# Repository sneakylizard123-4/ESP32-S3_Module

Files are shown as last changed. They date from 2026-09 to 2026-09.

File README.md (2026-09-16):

# ESP32-S3 Module

A Feather-like ESP32-S3 Module with IP5306 Battery charging and a built in Neopixel

## Custom Features
- IP5306 PMIC
- Neopixel, User and Power led
- ESP32-S3-1/1U MCU

## PCB Design

The Module is a 4 layer pcb with a dedicated ground inner layer

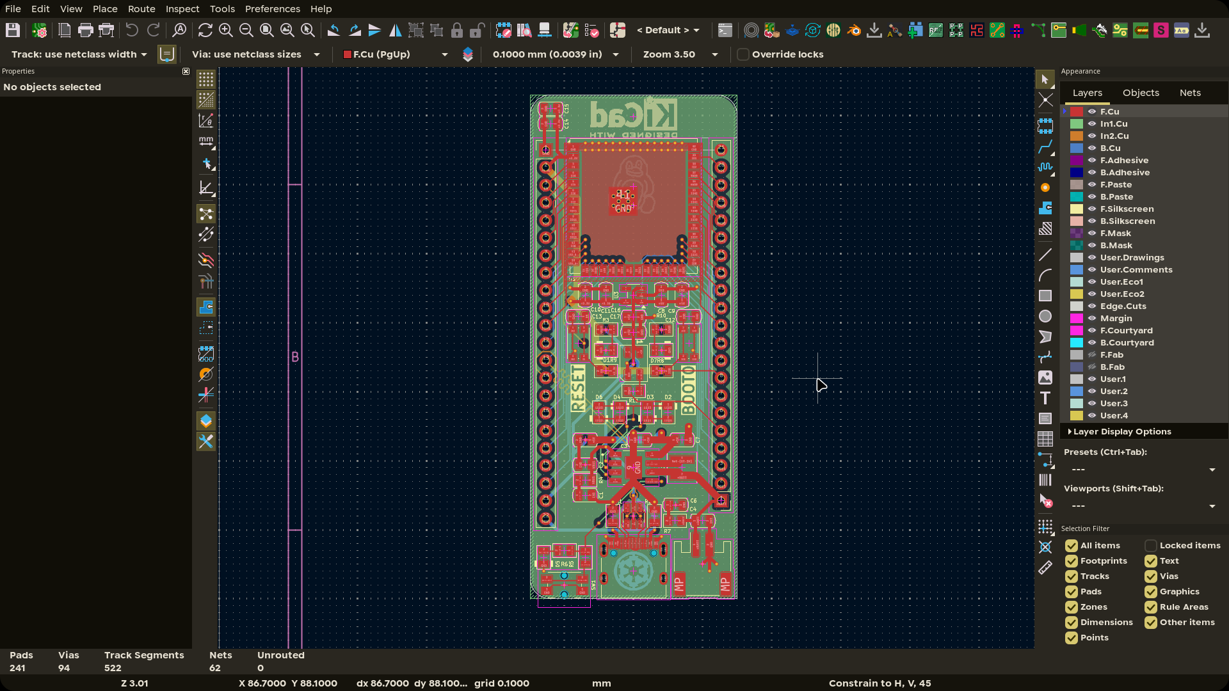
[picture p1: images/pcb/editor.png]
PCB 3D / layout image


It is built off the ESP32-S3 series MCU to support WiFi/Bluetooth/Zigbee
It has built in USB ESD protection.
It can be programmed using UART/FTDI or throught the ESP32-S3's Native USB.

## Firmware

As the Module uses an ESP32, it can be programmed using ESP-IDF, Arduino IDE, or Platformio.
To enter program mode:
1. Hold BOOT0
2. Press RESET
3. Release BOOT0
4. Start Flashing

## BOM (Bill of Materials)

| Ref | Value | LCSC # | MPN | Manufacturer | Footprint | Qty | Unit $ | Ext $ | Link |
|-----|---|---|-----|---|---|-----|---|---|---|
| C1,C2,C4,C6,C9,C11,C15,C17 | 10uF 25V X5R | C15850 | CL21A106KAYNNNE | Samsung | 0805 | 8 | 0.0871 | 0.6968 | [LCSC](https://www.lcsc.com/product-detail/C15850.html) |
| C8,C10,C12,C13,C14,C16 | 100nF 50V X7R | C1711 | CC0805KRX7R9BB104 | YAGEO | 0805 | 6 | 0.0266 | 0.1596 | [LCSC](https://www.lcsc.com/product-detail/C1711.html) |
| C3,C5,C7 | 22uF 25V X5R | C86816 | GRM21BR61E226ME44L | muRata | 0805 | 3 | 0.0698 | 0.2094 | [LCSC](https://www.lcsc.com/product-detail/C86816.html) |
| D1-D7 | Orange LED 0805 | C965813 | XL-2012UOC | XINGLIGHT | 0805 | 7 | 0.0096 | 0.0672 | [LCSC](https://www.lcsc.com/product-detail/C965813.html) |
| D8 | WS2812B | C2761795 | WS2812B-B/T | Worldsemi | PLCC4 5050 | 1 | 0.0940 | 0.0940 | [LCSC](https://www.lcsc.com/product-detail/C2761795.html) |
| J1 | USB-C Receptacle 16P | C165948 | TYPE-C-31-M-12 | Korean Hroparts Elec | SMD | 1 | 0.1724 | 0.1724 | [LCSC](https://www.lcsc.com/product-detail/C165948.html) |
| J2 | JST PH 2P 2mm | C131337 | B2B-PH-K-S(LF)(SN) | JST | Through Hole | 1 | 0.0356 | 0.0356 | [LCSC](https://www.lcsc.com/product-detail/C131337.html) |
| J3 | Pin Header 1x22 2.54mm | C41375941 | HC-PZ254-11.5L-1x22PZ | Hong Cheng | Through Hole | 1 | 0.1200 | 0.1200 | [LCSC](https://www.lcsc.com/product-detail/C41375941.html) |
| J4 | Pin Header 1x21 2.54mm | C49569644 | 2011-1X21G00SB | WingTAT | Through Hole | 1 | 0.1000 | 0.1000 | [LCSC](https://www.lcsc.com/product-detail/C49569644.html) |
| L1 | 1uH Shielded Inductor | C5355380 | XFL4020-102MEC | Coilcraft | SMD 4x4mm | 1 | 2.5134 | 2.5134 | [LCSC](https://www.lcsc.com/product-detail/C5355380.html) |
| R1,R2 | 5.1k 1% 0805 | C27834 | 0805W8F5101T5E | UNI-ROYAL | 0805 | 2 | 0.0065 | 0.0130 | [LCSC](https://www.lcsc.com/product-detail/C27834.html) |
| R3,R5,R6,R8,R9,R10 | 10k 1% 0805 | C2907219 | FRC0805F1002TS | FOJAN | 0805 | 6 | 0.0035 | 0.0210 | [LCSC](https://www.lcsc.com/product-detail/C2907219.html) |
| R11 | 330 1% 0805 | C2889518 | 0805 1% 330 OHM | VO | 0805 | 1 | 0.0050 | 0.0050 | [LCSC](https://www.lcsc.com/product-detail/C2889518.html) |
| R4,R7 | 2R 1% 0805 | C114246 | RC0805FR-072RL | YAGEO | 0805 | 2 | 0.0261 | 0.0522 | [LCSC](https://www.lcsc.com/product-detail/C114246.html) |
| SW1 | Tactile Switch EVQPUD | C388885 | EVQPUD02K | PANASONIC | SMD | 1 | 0.2299 | 0.2299 | [LCSC](https://www.lcsc.com/product-detail/C388885.html) |
| SW2,SW3 | Tactile Switch KMR2 | C72443 | KMR221GLFS | C&K | SMD | 2 | 0.6515 | 1.3030 | [LCSC](https://www.lcsc.com/product-detail/C72443.html) |
| U1 | USBLC6-2SC6 | C7519 | USBLC6-2SC6 | ST | SOT-23-6 | 1 | 0.0896 | 0.0896 | [LCSC](https://www.lcsc.com/product-detail/C7519.html) |
| U2 | IP5306 | C181692 | IP5306 | INJOINIC | ESOP-8 | 1 | 0.2989 | 0.2989 | [LCSC](https://www.lcsc.com/product-detail/C181692.html) |
| U3 | TLV75733PDBV | C485517 | TLV75733PDBVR | TI | SOT-23-5 | 1 | 0.1819 | 0.1819 | [LCSC](https://www.lcsc.com/product-detail/C485517.html) |
| U4 | ESP32-S3-WROOM-1U | C2913202 | ESP32-S3-WROOM-1-N8 | ESPRESSIF | SMD WROOM | 1 | 3.1300 | 3.1300 | [LCSC](https://www.lcsc.com/product-detail/C2913202.html) |
| PCB | Bare PCB | — | — | — | — | 1 | 1.5000 | 1.5000 | — |
| **Total** | — | — | — | — | — | **49** | — | **10.9929** | — |

Full CSVs: [LCSC BOM](BOM.csv)
[KiCad generated BOM](kicad/production/bom.csv)
[Pick and place](kicad/production/positions.csv)

## Production

This board assumes JLCPCB's standard 4 layer
- HASL Lead Free
- 1.6mm thick board

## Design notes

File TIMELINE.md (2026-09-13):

# Timeline

Chronology of the ESP32-S3 Module design work, reconstructed from KiCad Local History (`kicad/.history`, 672 auto-snapshots, all authored by "KiCad") and the project git history (`esp32-s3` repo, 3 commits by sneakylizard123-4). All times are local (UTC-7).

## Sep 2, 2026 (evening)

- 21:05: Project started. Root schematic created in KiCad: initial autosave followed by 3 quick saves. First components placed on a single flat sheet. (~5 min)

## Sep 3, 2026 (morning)

- 11:09-11:10: Short schematic session, more components added to the root sheet. (~5 min)

## Sep 13, 2026 (main work day)

### Schematic build-out (10:53 - 11:21)

- 10:53-11:12: Heavy edit burst on the root schematic (~64 saves). Full design laid out on one sheet: ESP32-S3-WROOM-1U MCU, USB-C with ESD clamp and CC resistors, IP5306 power management, TLV75733 3.3V LDO, header breakouts, buttons, LEDs.
- 11:13: PCB file created from the schematic in the PCB editor, then back to schematic work.
- 11:14-11:21: Final pass on the root sheet (net labels, cleanup).

### Hierarchical refactor (11:22 - 11:37)

- 11:22-11:25: Split the flat design into hierarchical subsheets. Creation order by first save: `usb.kicad_sch` (11:22), `power.kicad_sch` (11:23), `esp32.kicad_sch` (11:24), `connector.kicad_sch` (11:25). Root sheet now holds the 4 sheet symbols.
- 11:26-11:29: Wiring the sheet symbols and kicad_pcb library/footprint sync on the root sheet.
- 11:30-11:37: Power subsheet brought up in detail (IP5306 battery charger/boost, LDO, inductive buck components, status LEDs).

### Subsheet polish + first layout (11:39 - 12:25)

- 11:39-11:45: Round of edits across all four subsheets; PCB footprint sync starts.
- 11:42-11:58: Early PCB placement: footprints dropped and rough positioning on the board.
- 11:59-12:01: Schematic fixes needed to match footprint pins.
- 12:02-12:16: ESP32 subsheet detail work (pull-up resistors, decoupling, button wiring, WS2812B LED), connector sheet edits.
- 12:17-12:25: Continued component placement on the PCB.
- (_break, ~1 hour_)

### Board layout (13:26 - 13:56)

- 13:26-13:56: Long, steady PCB session - component placement finalized across the board (relays, ~90 saves). Occasional connector subsheet edits at 13:26 while iterating on the board.

### Board routing (14:14 - 15:19)

- 14:14-14:16: A couple more connector/power sheet touches, then pure PCB work.
- 14:17-14:24: Routing burst, heavy activity (~8 saves/min).
- 14:25-14:34: Routing continues (edge pours, power nets).
- 14:35-14:37: Last schematic tweaks on connector and usb subsheets to fix layout-drive issues; board re-synced.
- 14:38-15:19: Final routing marathon (~150 saves). Ends with PCB Save at 15:19:10, then production output generated at 15:19: `production/ESP32-S3_Module.zip` (gerbers), `bom.csv`, `positions.csv`, `designators.csv`, `netlist.ipc`.

### Packaging (15:19 - 15:42)

- 15:21: STEP 3D model exported to `cad/ESP32-S3_Module.step` (6.3 MB, board + component 3D models).
- 15:35: Project git repo initialized. First commit `e5d1c9f` "start": full KiCad sources, production files, STEP, README skeleton, and 7 rendered PNGs (5 schematic sheets + top/bottom PCB renders).
- 15:38: Commit `6953c8a` "readm": README trimmed/edited.
- ~15:39-15:41: PCB editor screenshot captured (`images/pcb/editor.png`). Empty `BOM.csv` and `JOURNAL.md` placeholders created.
- 15:42: Commit `c15c209` "a": screenshots reorganized into `images/schematic/`, `images/renders/`, `images/pcb/`, plus the README/BOM/JOURNAL updates.

## Totals (approx.)

- Sep 2: ~5 min
- Sep 3: ~5 min
- Sep 13: ~4 h 20 min across the day (schematic ~1.5 h, layout+route ~2.5 h, breaks excluded)

## Sources

- `kicad/.history` - KiCad Local History git repo (672 snapshots, Sep 2 -> Sep 13) by "KiCad"
- Project git repo - 3 commits (`start`, `readm`, `a`) by sneakylizard123-4, Sep 13 15:35-15:42

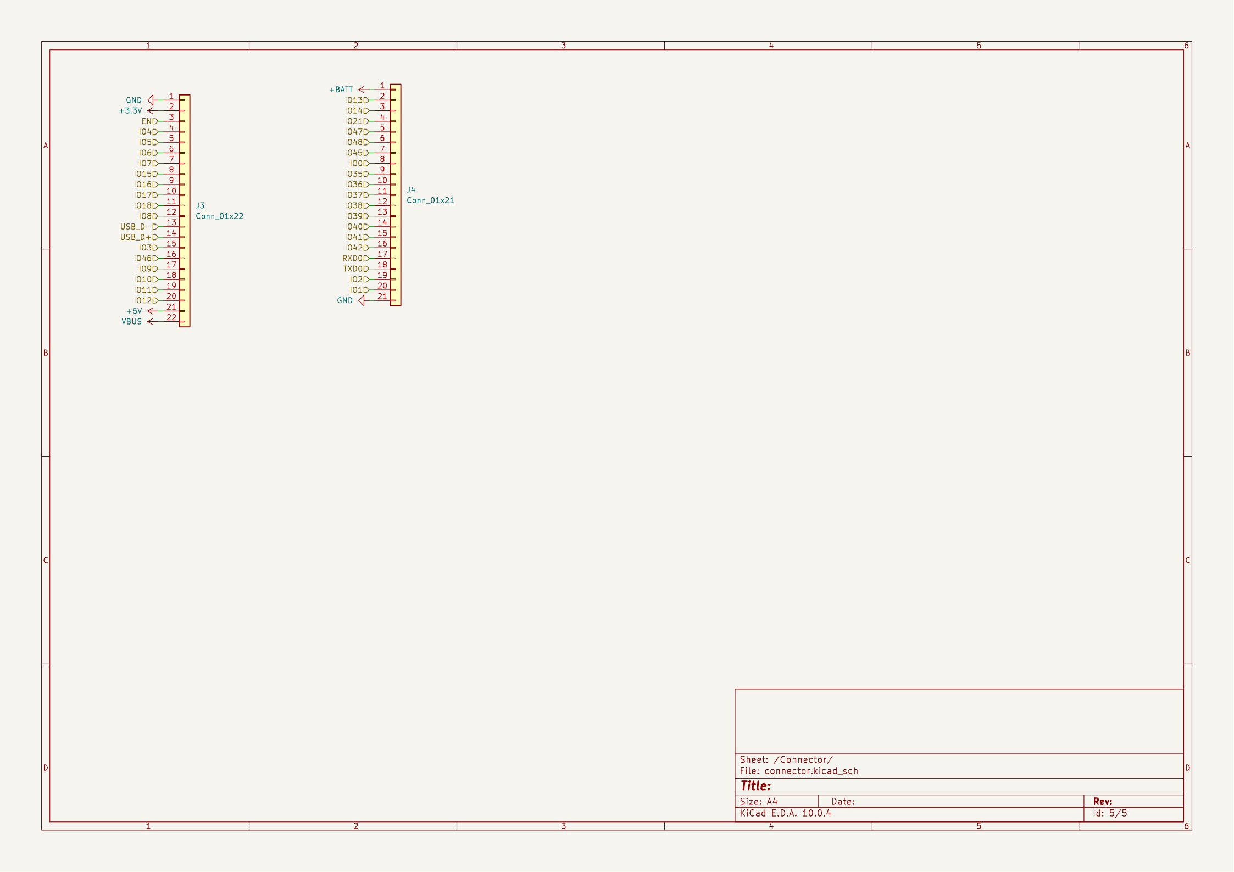
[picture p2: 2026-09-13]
images/schematic/05-connector.png

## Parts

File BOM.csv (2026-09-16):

Ref | Value | LCSC# | MPN | Manufacturer | Footprint | Qty | Unit Price($) | Ext Price($) | Supplier Link
C1, C11, C15, C17, C2, C4, C6, C9 | 10uF 25V X5R | C15850 | CL21A106KAYNNNE | Samsung | 0805 | 8 | 0.0871 | 0.6968 | https://www.lcsc.com/product-detail/C15850.html
C10, C12, C13, C14, C16, C8 | 100nF 50V X7R | C1711 | CC0805KRX7R9BB104 | YAGEO | 0805 | 6 | 0.0266 | 0.1596 | https://www.lcsc.com/product-detail/C1711.html
C3, C5, C7 | 22uF 25V X5R | C86816 | GRM21BR61E226ME44L | muRata | 0805 | 3 | 0.0698 | 0.2094 | https://www.lcsc.com/product-detail/C86816.html
D1, D2, D3, D4, D5, D6, D7 | Orange LED 0805 | C965813 | XL-2012UOC | XINGLIGHT | 0805 | 7 | 0.0096 | 0.0672 | https://www.lcsc.com/product-detail/C965813.html
D8 | WS2812B | C2761795 | WS2812B-B/T | Worldsemi | PLCC4 5050 | 1 | 0.0940 | 0.0940 | https://www.lcsc.com/product-detail/C2761795.html
J1 | USB-C Receptacle 16P | C165948 | TYPE-C-31-M-12 | Korean Hroparts Elec | SMD | 1 | 0.1724 | 0.1724 | https://www.lcsc.com/product-detail/C165948.html
J2 | JST PH 2P 2mm | C131337 | B2B-PH-K-S(LF)(SN) | JST | Through Hole | 1 | 0.0356 | 0.0356 | https://www.lcsc.com/product-detail/C131337.html
J3 | Pin Header 1x22 2.54mm | C41375941 | HC-PZ254-11.5L-1x22PZ | Hong Cheng | Through Hole | 1 | 0.1200 | 0.1200 | https://www.lcsc.com/product-detail/C41375941.html
J4 | Pin Header 1x21 2.54mm | C49569644 | 2011-1X21G00SB | WingTAT | Through Hole | 1 | 0.1000 | 0.1000 | https://www.lcsc.com/product-detail/C49569644.html
L1 | 1uH Shielded Inductor | C5355380 | XFL4020-102MEC | Coilcraft | SMD 4x4mm | 1 | 2.5134 | 2.5134 | https://www.lcsc.com/product-detail/C5355380.html
R1, R2 | 5.1k 1% 0805 | C27834 | 0805W8F5101T5E | UNI-ROYAL | 0805 | 2 | 0.0065 | 0.0130 | https://www.lcsc.com/product-detail/C27834.html
R10, R3, R5, R6, R8, R9 | 10k 1% 0805 | C2907219 | FRC0805F1002TS | FOJAN | 0805 | 6 | 0.0035 | 0.0210 | https://www.lcsc.com/product-detail/C2907219.html
R11 | 330 1% 0805 | C2889518 | 0805 1% 330 OHM | VO | 0805 | 1 | 0.0050 | 0.0050 | https://www.lcsc.com/product-detail/C2889518.html
R4, R7 | 2R 1% 0805 | C114246 | RC0805FR-072RL | YAGEO | 0805 | 2 | 0.0261 | 0.0522 | https://www.lcsc.com/product-detail/C114246.html
SW1 | Tactile Switch EVQPUD | C388885 | EVQPUD02K | PANASONIC | SMD | 1 | 0.2299 | 0.2299 | https://www.lcsc.com/product-detail/C388885.html
SW2, SW3 | Tactile Switch KMR2 | C72443 | KMR221GLFS | C&K | SMD | 2 | 0.6515 | 1.3030 | https://www.lcsc.com/product-detail/C72443.html
U1 | USBLC6-2SC6 | C7519 | USBLC6-2SC6 | ST | SOT-23-6 | 1 | 0.0896 | 0.0896 | https://www.lcsc.com/product-detail/C7519.html
U2 | IP5306 | C181692 | IP5306 | INJOINIC | ESOP-8 | 1 | 0.2989 | 0.2989 | https://www.lcsc.com/product-detail/C181692.html
U3 | TLV75733PDBV | C485517 | TLV75733PDBVR | TI | SOT-23-5 | 1 | 0.1819 | 0.1819 | https://www.lcsc.com/product-detail/C485517.html
U4 | ESP32-S3-WROOM-1U | C2913202 | ESP32-S3-WROOM-1-N8 | ESPRESSIF | SMD WROOM | 1 | 3.1300 | 3.1300 | https://www.lcsc.com/product-detail/C2913202.html
PCB | Bare PCB |  |  |  |  | 1 | 1.5000 | 1.5000
Total |  |  | Components (9.4929) + PCB (1.50) = Total |  |  |  |  | 10.9929

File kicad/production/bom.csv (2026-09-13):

Designator | Footprint | Quantity | Value | LCSC Part #
C1, C11, C15, C17, C2, C4, C6, C9 | 0805 | 8 | 10uF
C10, C12, C13, C14, C16, C8 | 0805 | 6 | 100nF
C3, C5, C7 | 0805 | 3 | 22uF
D1, D2, D3, D4, D5, D6, D7 | 0805 | 7 | LED
D8 | LED_WS2812B-Mini_PLCC4_3.5x3.5mm | 1 | WS2812B
J1 | USB_C_Receptacle_HRO_TYPE-C-31-M-12 | 1 | USB_C_Receptacle_USB2.0_16P
J2 | JST_PH_S2B-PH-SM4-TB_1x02-1MP_P2.00mm_Horizontal | 1 | Conn_01x02
J3 | PinHeader_1x22_P2.54mm_Vertical | 1 | Conn_01x22
J4 | PinHeader_1x21_P2.54mm_Vertical | 1 | Conn_01x21
L1 | L_Coilcraft_XxL4020 | 1 | 1uH XFL4020-102MEC
R1, R2 | 0805 | 2 | 5.1k
R10, R3, R5, R6, R8, R9 | 0805 | 6 | 10k
R11 | 0805 | 1 | 330
R4, R7 | 0805 | 2 | 2
SW1 | Panasonic_EVQPUM_EVQPUD | 1 | SW_Push
SW2, SW3 | SW_Push_1P1T_NO_CK_KMR2 | 2 | SW_Push
U1 | SOT-23-6 | 1 | USBLC6-2SC6
U2 | SOP127P600X165-9N | 1 | IP5306
U3 | SOT-23-5 | 1 | TLV75733PDBV
U4 | ESP32-S3-WROOM-1U | 1 | ESP32-S3-WROOM-1

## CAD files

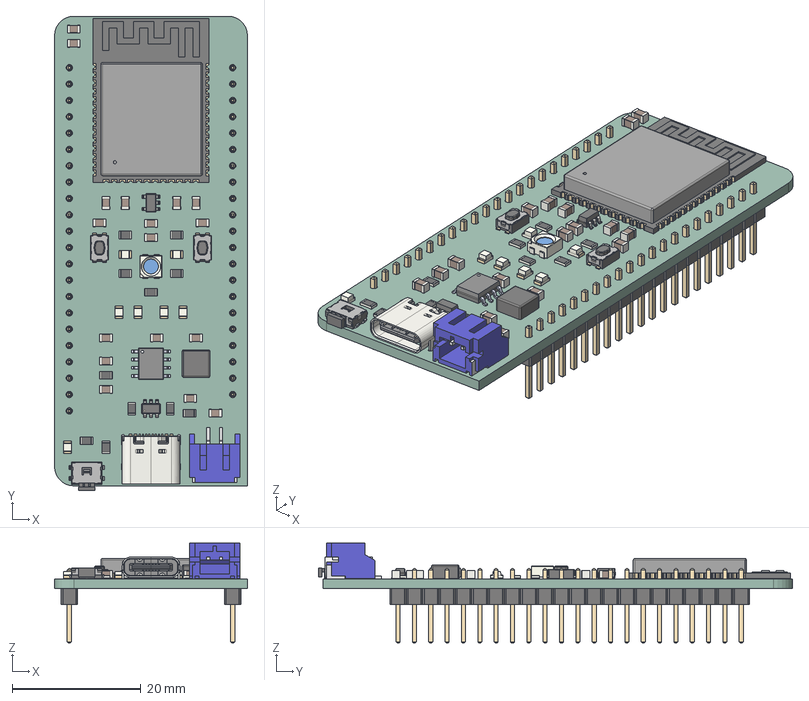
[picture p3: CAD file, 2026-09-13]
cad/ESP32-S3_Module.step
30.0 x 73.8 x 15.5 mm
SW_Push_1P1T_NO_CK_KMR2 x 2
C_0805_2012Metric x 17
LED_0805_2012Metric x 7
R_0805_2012Metric x 11
ESP32-S3-WROOM-1
IP5306
Panasonic_EVQPUM_EVQPUD
SOT-23-6
SOT-23-5
S2B-PH-SM4
L_Coilcraft_XAL4020-XXX
USB_C_Receptacle_16P_TopMnt_Horizontal_GCT_USB4105-xx-A
LED_WS2812B-Mini_PLCC4_3.5x3.5mm_P1.8mm
PinHeader_1x22_P254mm_Vertical
PinHeader_1x21_P254mm_Vertical
ESP32-S3_Module_PCB

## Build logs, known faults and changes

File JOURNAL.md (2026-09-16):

---
title: ESP32-S3 Module
author: sneakylizard123-4
description: Like a Feather
created_at: 2026-09-02
---

# September 2

Started the ESP32-S3 Project.
I wanted a quick and easy way to prototype my projects and all of my other esp32's were either:
1. Not esp32 (esp8266)
2. No USB (needed FTDI)
3. Not esp32-s3

Placed first components like USB-C and the main ESP32 MCU

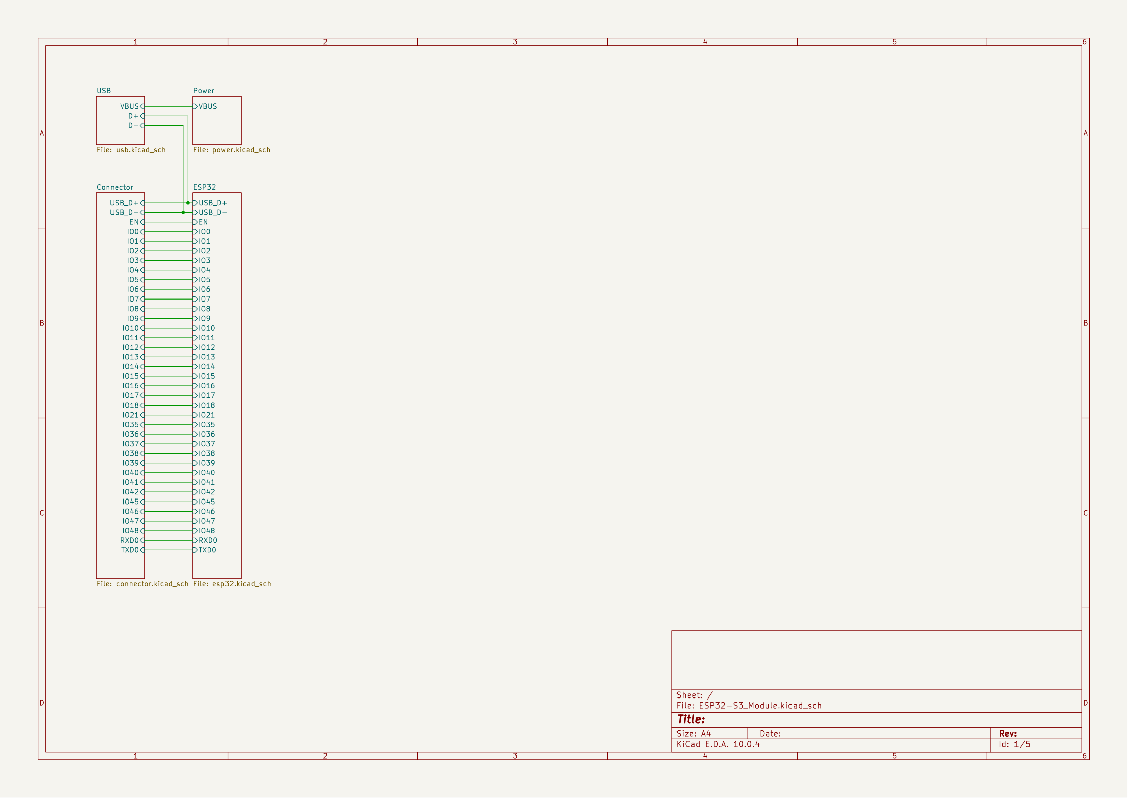
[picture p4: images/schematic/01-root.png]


**Total Time Spent: 2 hours**

# September 3

More work done on schematic, like the 3.3v regulator and capacitors/resistors

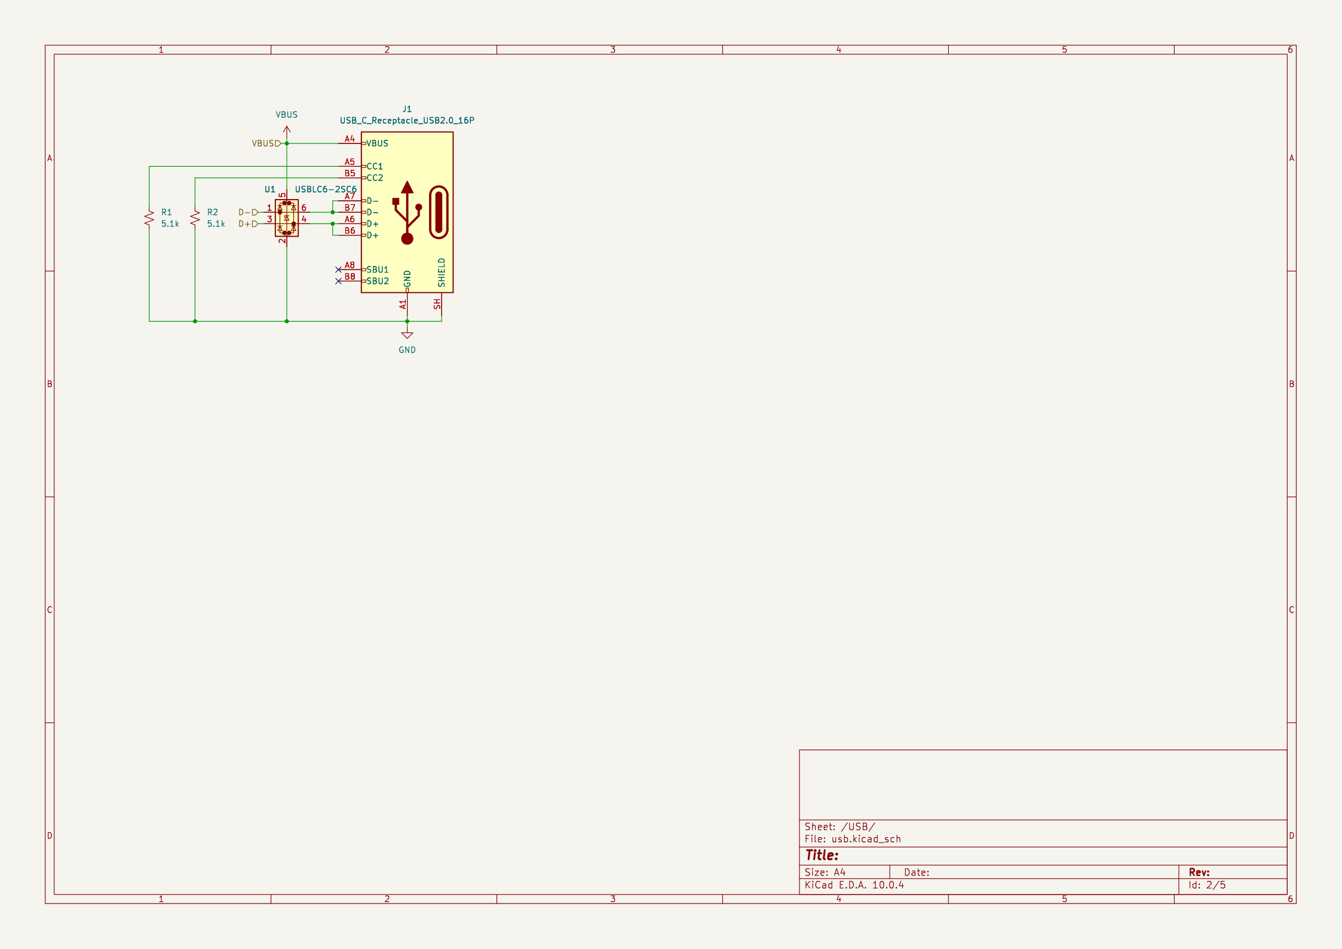
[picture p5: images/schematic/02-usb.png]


**Total Time Spent: 2 hour**

# September 12

Full design laid out on main sheet:
- ESP32-S3-WROOM-1 MCU
- USB-C with ESD protection and CC resistors
- IP5306 Power management IC
- TLV73733PDRV 3.3v LDO
- Header pins
- Buttons for Reset and Boot0

Started PCB to test fit parts, then went back to do more schematic work.
Did a final pass on the root sheet, net labels andd cleaning

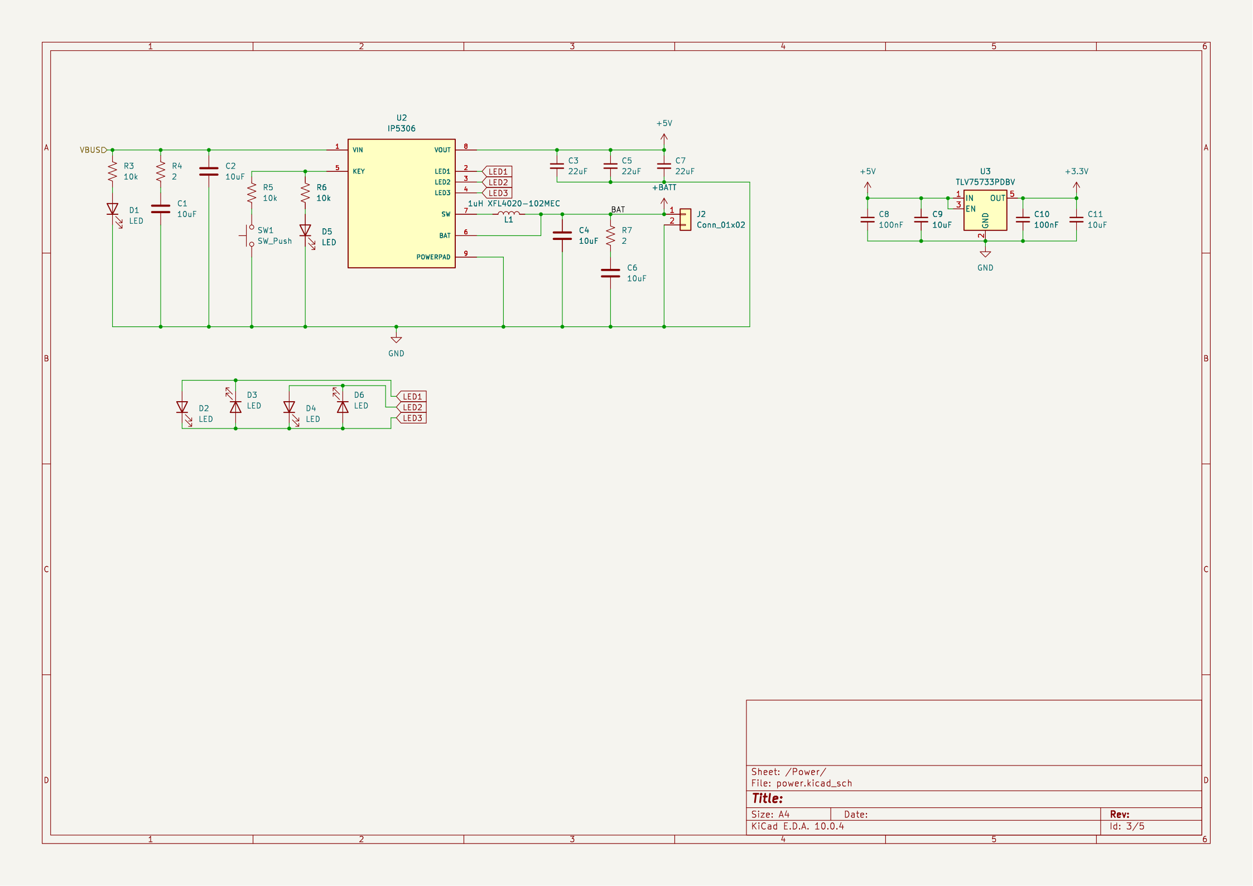
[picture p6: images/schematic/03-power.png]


**Total Time Spent: 3 hours**

# September 13

Split the design into subsheets:
- Root
- USB
- Power
- ESP32
- Connector

Copied IP5306 section from existing IP5306 projects

fixed footprints

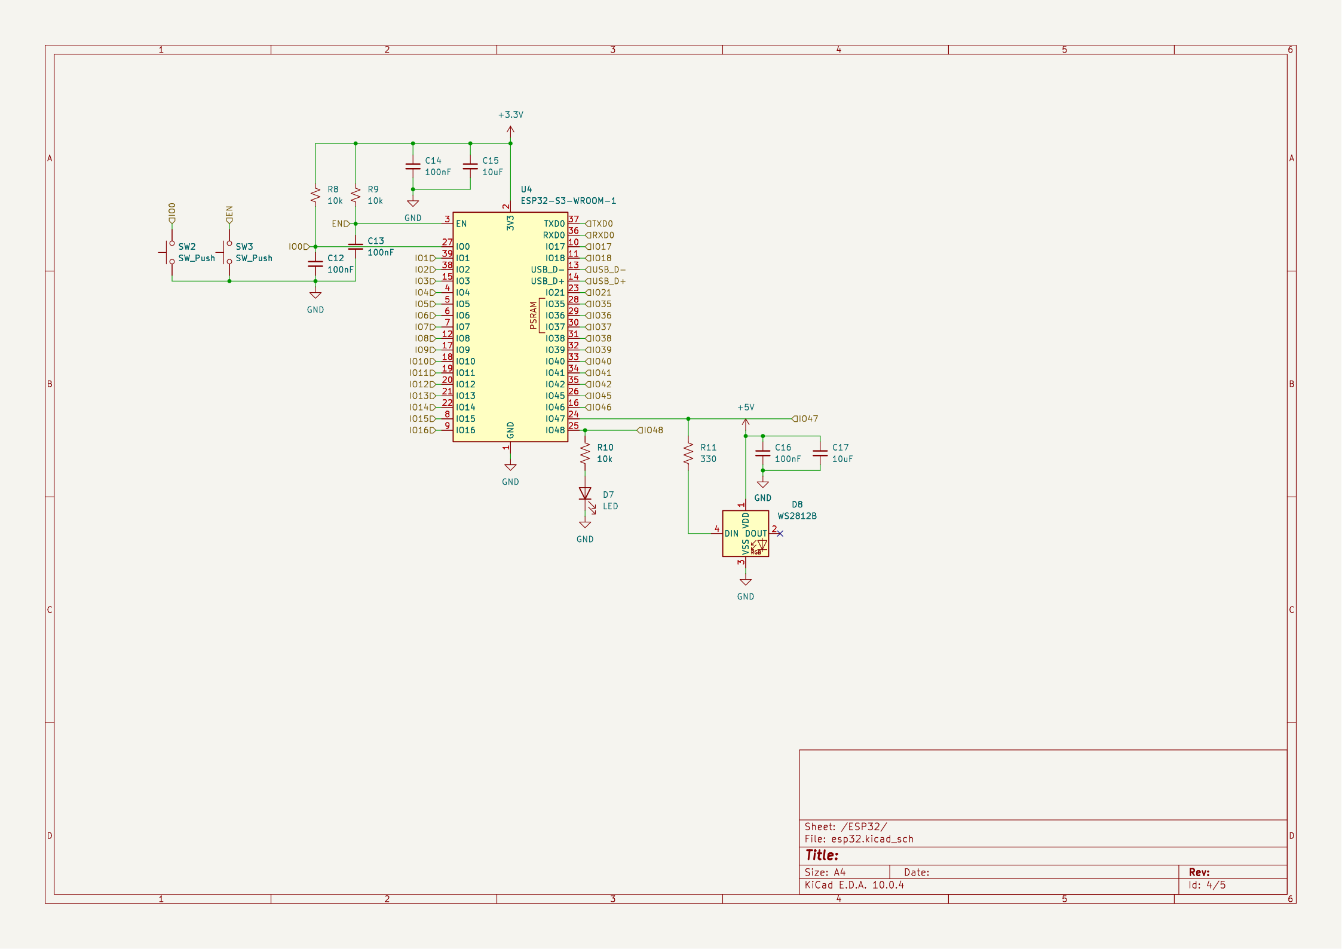
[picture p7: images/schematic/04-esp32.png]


## Started PCB layout

Rough positioning on the board
Schematic fixes to match footprints on the board
Worked on esp32 pull up resistors
connector sheet edits for more power connections
test ip5306 layout

beefed up traces for power connections
rounded pcb edges
ground zone fill
generated production output



## Packaging

generated step model
git repo initialized
took screenshots of everything
made readme
made journal

Still need to work on BOM

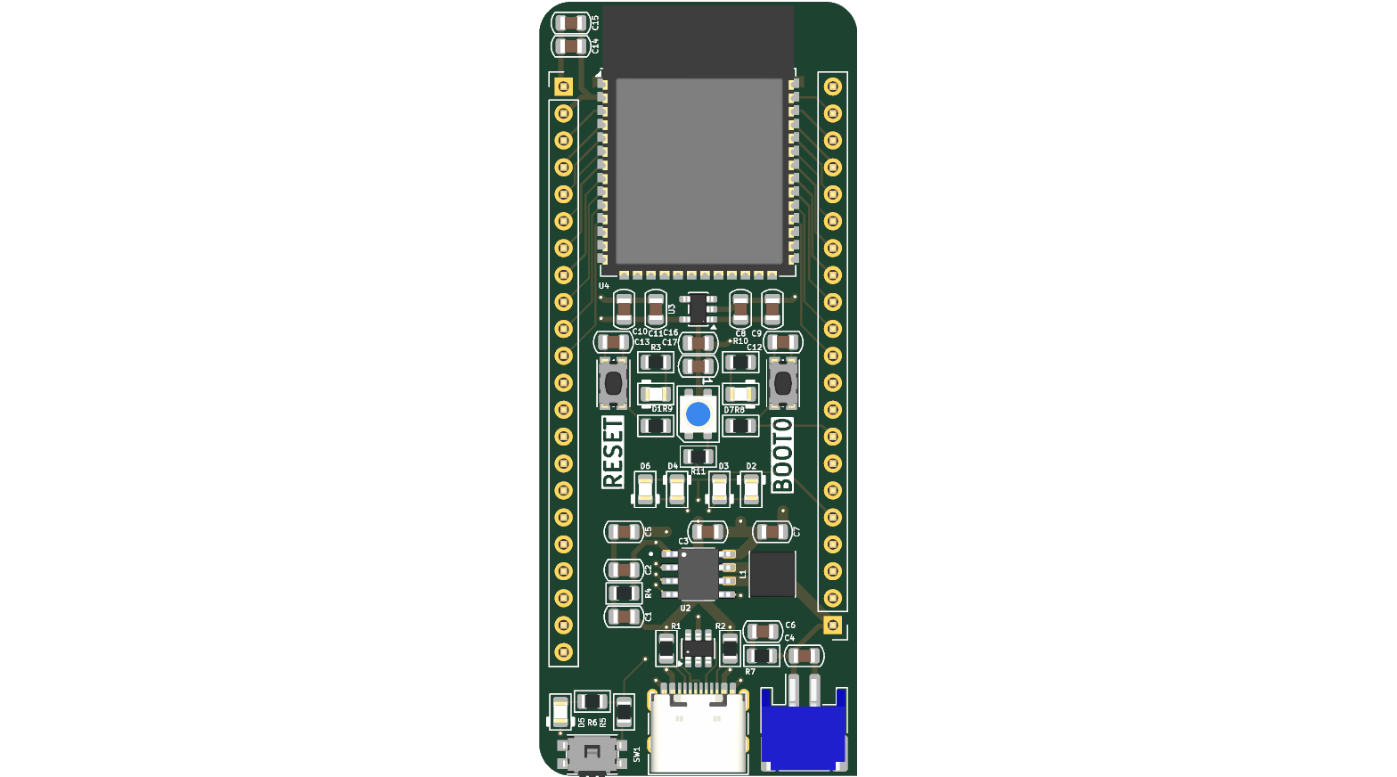
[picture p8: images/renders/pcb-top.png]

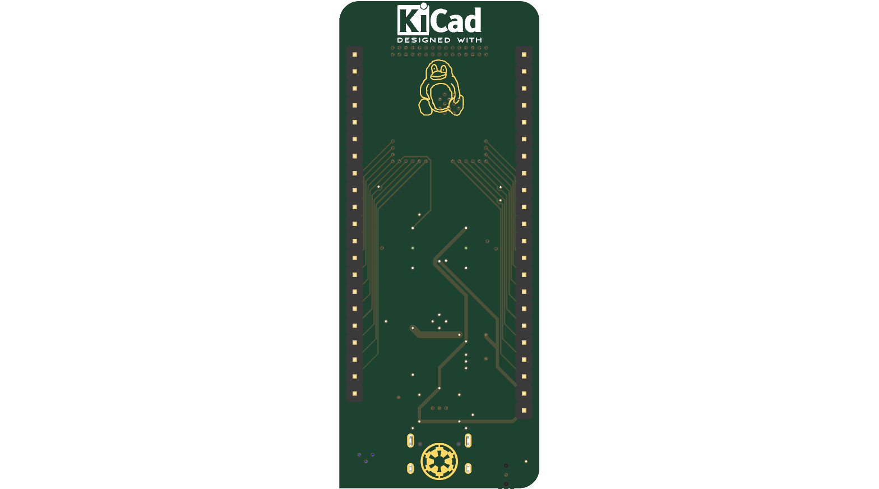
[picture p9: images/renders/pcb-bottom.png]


**Total Time Spent: 4 hours**

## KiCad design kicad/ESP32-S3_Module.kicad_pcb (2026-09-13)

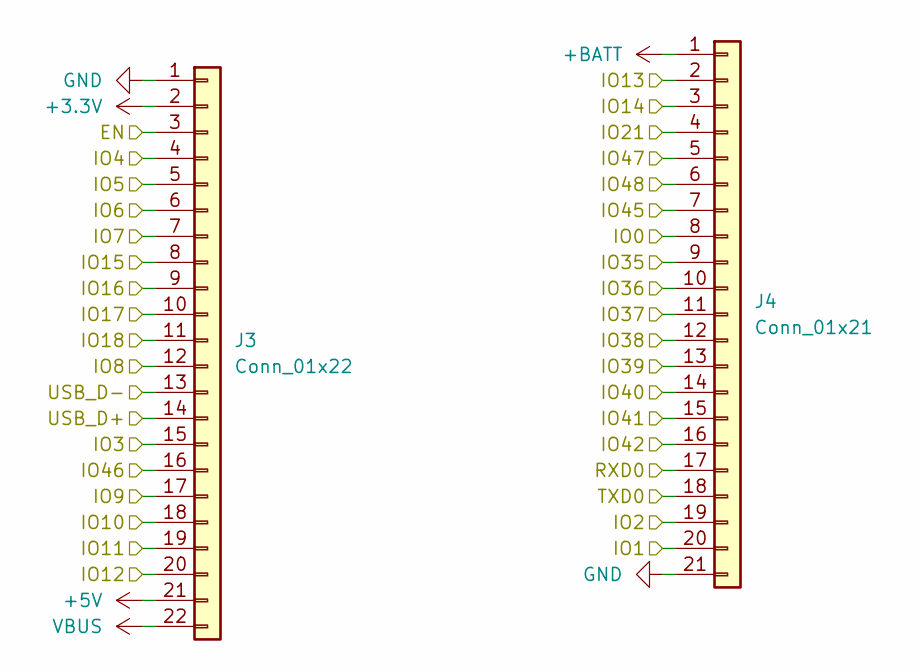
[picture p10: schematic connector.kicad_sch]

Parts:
J3: Conn_01x22; PinHeader_1x22_P2.54mm_Vertical
J4: Conn_01x21; PinHeader_1x21_P2.54mm_Vertical

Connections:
+3.3V: J3.2; also elsewhere on the board
+5V: J3.21; also elsewhere on the board
+BATT: J4.1; also elsewhere on the board
/Connector/EN: J3.3; also elsewhere on the board
/Connector/IO0: J4.8; also elsewhere on the board
/Connector/IO1: J4.20; also elsewhere on the board
/Connector/IO2: J4.19; also elsewhere on the board
/Connector/IO3: J3.15; also elsewhere on the board
/Connector/IO4: J3.4; also elsewhere on the board
/Connector/IO5: J3.5; also elsewhere on the board
/Connector/IO6: J3.6; also elsewhere on the board
/Connector/IO7: J3.7; also elsewhere on the board
/Connector/IO8: J3.12; also elsewhere on the board
/Connector/IO9: J3.17; also elsewhere on the board
/Connector/IO10: J3.18; also elsewhere on the board
/Connector/IO11: J3.19; also elsewhere on the board
/Connector/IO12: J3.20; also elsewhere on the board
/Connector/IO13: J4.2; also elsewhere on the board
/Connector/IO14: J4.3; also elsewhere on the board
/Connector/IO15: J3.8; also elsewhere on the board
/Connector/IO16: J3.9; also elsewhere on the board
/Connector/IO17: J3.10; also elsewhere on the board
/Connector/IO18: J3.11; also elsewhere on the board
/Connector/IO21: J4.4; also elsewhere on the board
/Connector/IO35: J4.9; also elsewhere on the board
/Connector/IO36: J4.10; also elsewhere on the board
/Connector/IO37: J4.11; also elsewhere on the board
/Connector/IO38: J4.12; also elsewhere on the board
/Connector/IO39: J4.13; also elsewhere on the board
/Connector/IO40: J4.14; also elsewhere on the board
/Connector/IO41: J4.15; also elsewhere on the board
/Connector/IO42: J4.16; also elsewhere on the board
/Connector/IO45: J4.7; also elsewhere on the board
/Connector/IO46: J3.16; also elsewhere on the board
/Connector/IO47: J4.5; also elsewhere on the board
/Connector/IO48: J4.6; also elsewhere on the board
/Connector/RXD0: J4.17; also elsewhere on the board
/Connector/TXD0: J4.18; also elsewhere on the board
/Connector/USB_D+: J3.14; also elsewhere on the board
/Connector/USB_D-: J3.13; also elsewhere on the board
GND: J3.1, J4.21; also elsewhere on the board
VBUS: J3.22; also elsewhere on the board

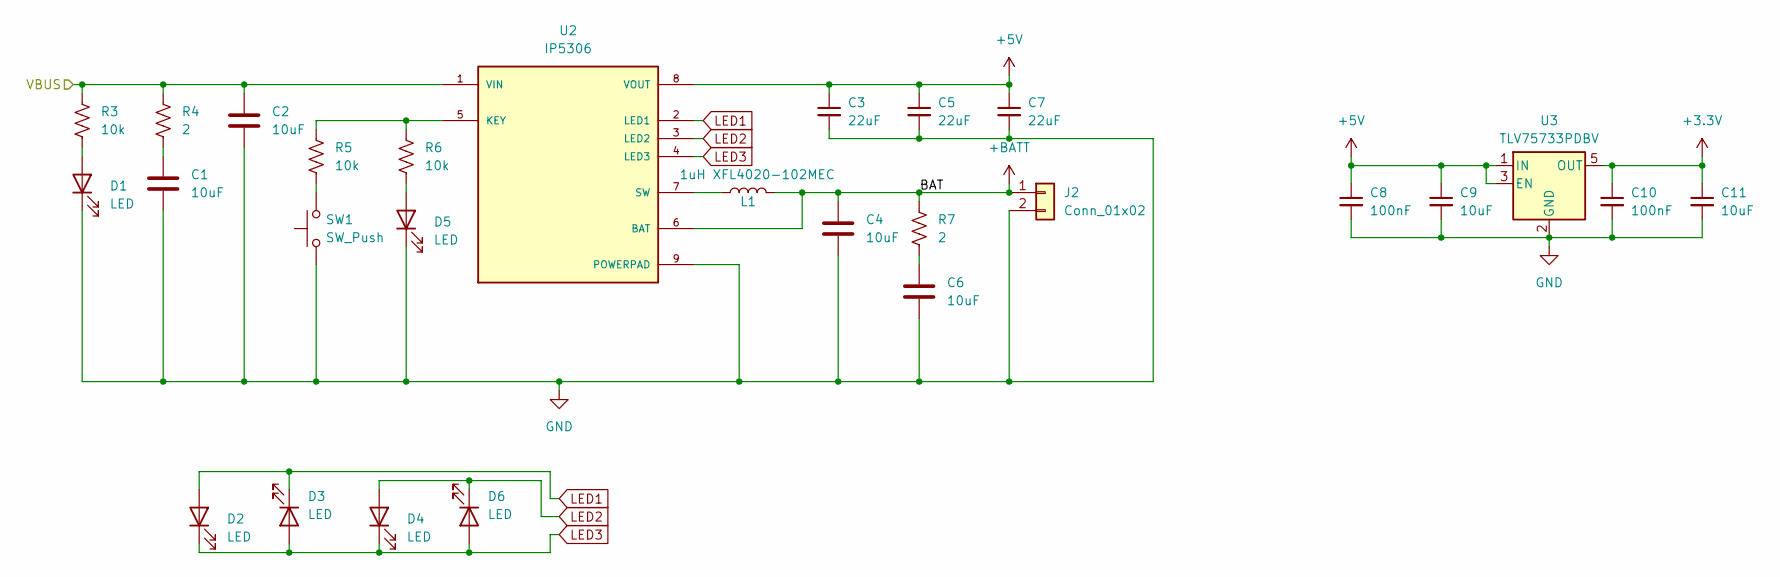
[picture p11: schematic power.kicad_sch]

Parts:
C1, C2, C4, C6, C9, C11: 10uF; C_0805_2012Metric
C3, C5, C7: 22uF; C_0805_2012Metric
C8, C10: 100nF; C_0805_2012Metric
D1, D2, D3, D4, D5, D6: LED; LED_0805_2012Metric
J2: Conn_01x02; JST_PH_S2B-PH-SM4-TB_1x02-1MP_P2.00mm_Horizontal
L1: 1uH XFL4020-102MEC; L_Coilcraft_XxL4020
R3, R5, R6: 10k; R_0805_2012Metric
R4, R7: 2; R_0805_2012Metric
SW1: SW_Push; Panasonic_EVQPUM_EVQPUD
U2: IP5306; SOP127P600X165-9N; PARTREV 1.31
U3: TLV75733PDBV; SOT-23-5

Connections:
+3.3V: C10.1, C11.1, U3.5 (OUT); also elsewhere on the board
+5V: C3.1, C5.1, C7.1, C8.1, C9.1, U2.8 (VOUT), U3.1 (IN), U3.3 (EN); also elsewhere on the board
+BATT: C4.1, J2.1, L1.2, R7.1, U2.6 (BAT); also elsewhere on the board
GND: C1.2, C2.2, C3.2, C4.2, C5.2, C6.2, C7.2, C8.2, C9.2, C10.2, C11.2, D1.1 (K), D5.1 (K), J2.2, SW1.1, U2.9 (POWERPAD), U3.2 (GND); also elsewhere on the board
LED1: D2.2 (A), D3.1 (K), U2.2 (LED1)
LED2: D4.2 (A), D6.1 (K), U2.3 (LED2)
LED3: D2.1 (K), D3.2 (A), D4.1 (K), D6.2 (A), U2.4 (LED3)
unnamed: C1.1, R4.2
unnamed: C6.1, R7.2
unnamed: D1.2 (A), R3.2
unnamed: D5.2 (A), R6.2
unnamed: R5.2, SW1.2
unnamed: R5.1, R6.1, U2.5 (KEY)
unnamed: L1.1, U2.7 (SW)
VBUS: C2.1, R3.1, R4.1, U2.1 (VIN); also elsewhere on the board

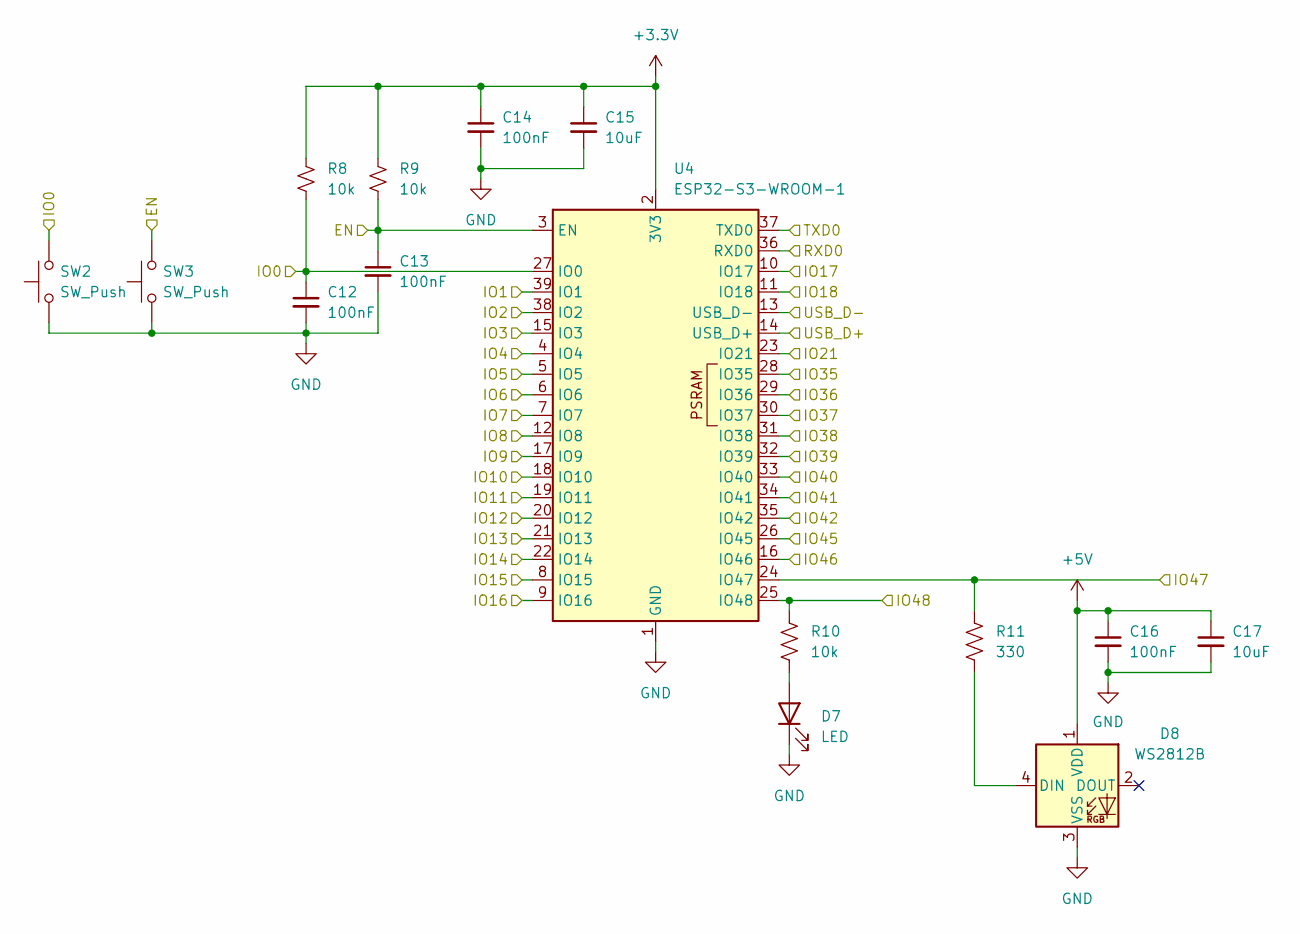
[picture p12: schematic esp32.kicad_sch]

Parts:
C12, C13, C14, C16: 100nF; C_0805_2012Metric
C15, C17: 10uF; C_0805_2012Metric
D7: LED; LED_0805_2012Metric
D8: WS2812B; LED_WS2812B-Mini_PLCC4_3.5x3.5mm
R8, R9, R10: 10k; R_0805_2012Metric
R11: 330; R_0805_2012Metric
SW2, SW3: SW_Push; SW_Push_1P1T_NO_CK_KMR2
U4: ESP32-S3-WROOM-1; ESP32-S3-WROOM-1U

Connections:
+3.3V: C14.1, C15.1, R8.1, R9.1, U4.2 (3V3); also elsewhere on the board
+5V: C16.1, C17.1, D8.1 (VDD); also elsewhere on the board
/Connector/EN: C13.1, R9.2, SW3.2, U4.3 (EN); also elsewhere on the board
/Connector/IO0: C12.1, R8.2, SW2.2, U4.27 (IO0); also elsewhere on the board
/Connector/IO1: U4.39 (IO1); also elsewhere on the board
/Connector/IO2: U4.38 (IO2); also elsewhere on the board
/Connector/IO3: U4.15 (IO3); also elsewhere on the board
/Connector/IO4: U4.4 (IO4); also elsewhere on the board
/Connector/IO5: U4.5 (IO5); also elsewhere on the board
/Connector/IO6: U4.6 (IO6); also elsewhere on the board
/Connector/IO7: U4.7 (IO7); also elsewhere on the board
/Connector/IO8: U4.12 (IO8); also elsewhere on the board
/Connector/IO9: U4.17 (IO9); also elsewhere on the board
/Connector/IO10: U4.18 (IO10); also elsewhere on the board
/Connector/IO11: U4.19 (IO11); also elsewhere on the board
/Connector/IO12: U4.20 (IO12); also elsewhere on the board
/Connector/IO13: U4.21 (IO13); also elsewhere on the board
/Connector/IO14: U4.22 (IO14); also elsewhere on the board
/Connector/IO15: U4.8 (IO15); also elsewhere on the board
/Connector/IO16: U4.9 (IO16); also elsewhere on the board
/Connector/IO17: U4.10 (IO17); also elsewhere on the board
/Connector/IO18: U4.11 (IO18); also elsewhere on the board
/Connector/IO21: U4.23 (IO21); also elsewhere on the board
/Connector/IO35: U4.28 (IO35); also elsewhere on the board
/Connector/IO36: U4.29 (IO36); also elsewhere on the board
/Connector/IO37: U4.30 (IO37); also elsewhere on the board
/Connector/IO38: U4.31 (IO38); also elsewhere on the board
/Connector/IO39: U4.32 (IO39); also elsewhere on the board
/Connector/IO40: U4.33 (IO40); also elsewhere on the board
/Connector/IO41: U4.34 (IO41); also elsewhere on the board
/Connector/IO42: U4.35 (IO42); also elsewhere on the board
/Connector/IO45: U4.26 (IO45); also elsewhere on the board
/Connector/IO46: U4.16 (IO46); also elsewhere on the board
/Connector/IO47: R11.1, U4.24 (IO47); also elsewhere on the board
/Connector/IO48: R10.1, U4.25 (IO48); also elsewhere on the board
/Connector/RXD0: U4.36 (RXD0); also elsewhere on the board
/Connector/TXD0: U4.37 (TXD0); also elsewhere on the board
/Connector/USB_D+: U4.14 (USB_D+); also elsewhere on the board
/Connector/USB_D-: U4.13 (USB_D-); also elsewhere on the board
GND: C12.2, C13.2, C14.2, C15.2, C16.2, C17.2, D7.1 (K), D8.3 (VSS), SW2.1, SW3.1, U4.1 (GND), U4.40 (GND), U4.41 (GND); also elsewhere on the board
unnamed: D7.2 (A), R10.2
unnamed: D8.4 (DIN), R11.2

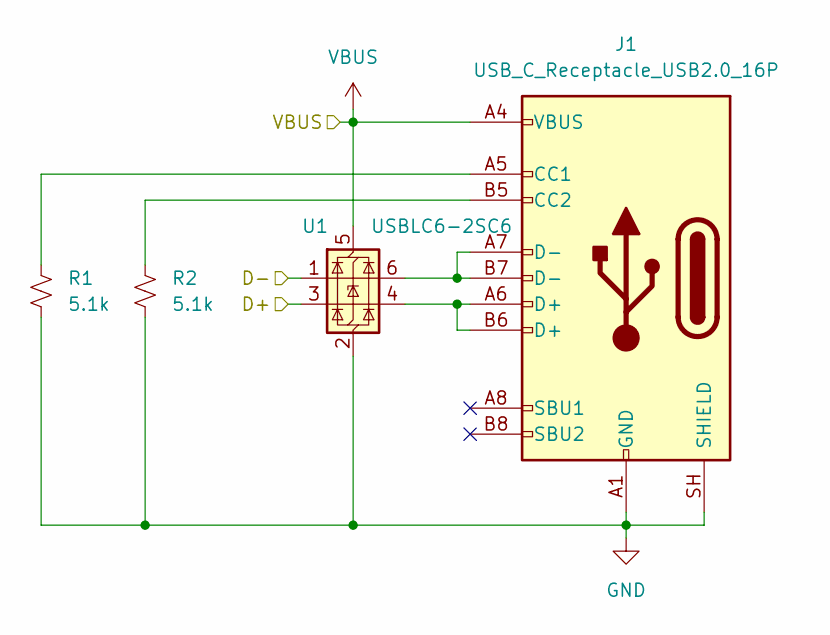
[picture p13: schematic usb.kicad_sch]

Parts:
J1: USB_C_Receptacle_USB2.0_16P; USB_C_Receptacle_HRO_TYPE-C-31-M-12
R1, R2: 5.1k; R_0805_2012Metric
U1: USBLC6-2SC6; SOT-23-6

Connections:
/Connector/USB_D+: U1.3 (I/O2); also elsewhere on the board
/Connector/USB_D-: U1.1 (I/O1); also elsewhere on the board
GND: J1.A1 (GND), J1.A12 (GND), J1.B1 (GND), J1.B12 (GND), J1.SH (SHIELD), R1.2, R2.2, U1.2 (GND); also elsewhere on the board
unnamed: J1.A5 (CC1), R1.1
unnamed: J1.B5 (CC2), R2.1
unnamed: J1.A6 (D+), J1.B6 (D+), U1.4 (I/O2)
unnamed: J1.A7 (D-), J1.B7 (D-), U1.6 (I/O1)
VBUS: J1.A4 (VBUS), J1.A9 (VBUS), J1.B4 (VBUS), J1.B9 (VBUS), U1.5 (VBUS); also elsewhere on the board

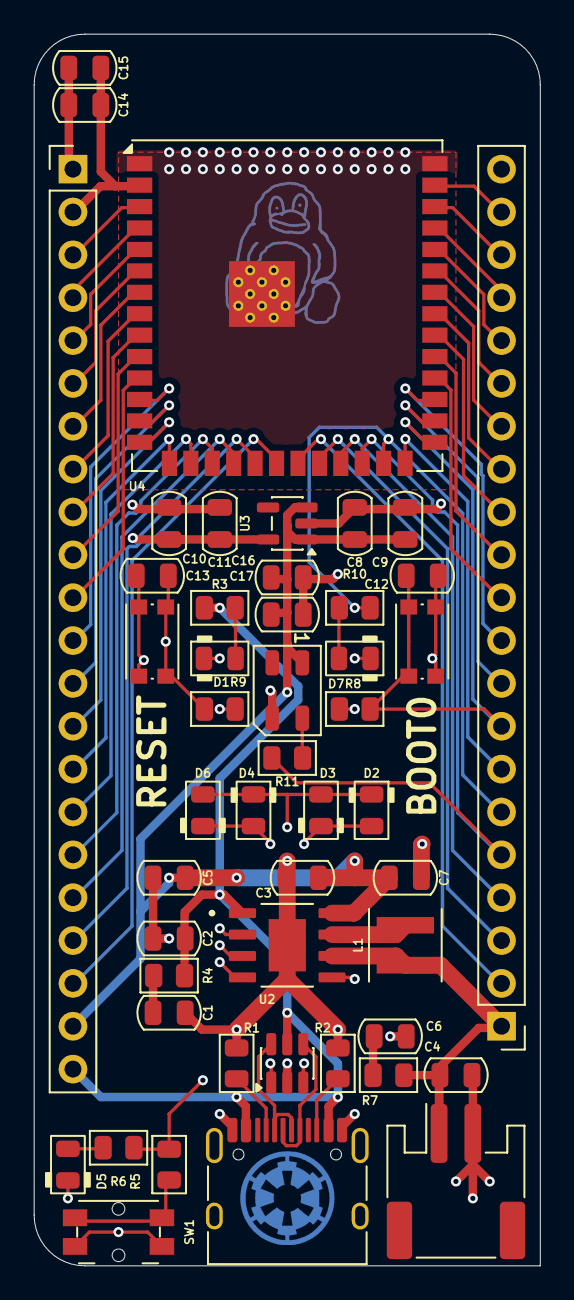
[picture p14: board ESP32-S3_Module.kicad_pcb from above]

Board: 4 copper layers, 30.0 x 73.0 mm, 48 parts (0 on the bottom side), 58 nets.

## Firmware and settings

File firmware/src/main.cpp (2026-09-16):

#include <Arduino.h>
#include <Adafruit_NeoPixel.h>

// D8 (WS2812B) -> IO47 via R11 (330R)
#define NEOPIXEL_PIN 47
// D7 (orange LED) -> IO48 via R10 (10k)
#define LED_PIN 48
#define NUM_LEDS 1

Adafruit_NeoPixel strip(NUM_LEDS, NEOPIXEL_PIN, NEO_GRB + NEO_KHZ800);

void setup() {
  pinMode(LED_PIN, OUTPUT);
  strip.begin();
  strip.setBrightness(50);
}

void loop() {
  static uint8_t hue = 0;

  // blink D7
  digitalWrite(LED_PIN, HIGH);
  strip.setPixelColor(0, strip.ColorHSV(hue * 256));
  strip.show();
  delay(250);

  digitalWrite(LED_PIN, LOW);
  strip.setPixelColor(0, strip.ColorHSV((hue + 85) * 256));
  strip.show();
  delay(250);

  hue++;
}

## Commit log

2026-09-16 add table bom
2026-10-23 add assembled image
